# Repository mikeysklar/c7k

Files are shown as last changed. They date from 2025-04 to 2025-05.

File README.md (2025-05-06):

# c7k

c7k
===

Chording 7 Key - I2C breakout

Ultra-Thin wearable one handed keyboard which can be used with a phone, tablet, computer even from a pocket. It is a full size keybaord in seven buttons.

I2C interface means easy connectivity to modern micrcontrollers and single board computers. This allows maximum flexibility for direct to controller, HID USB or HID BLE interfacing.

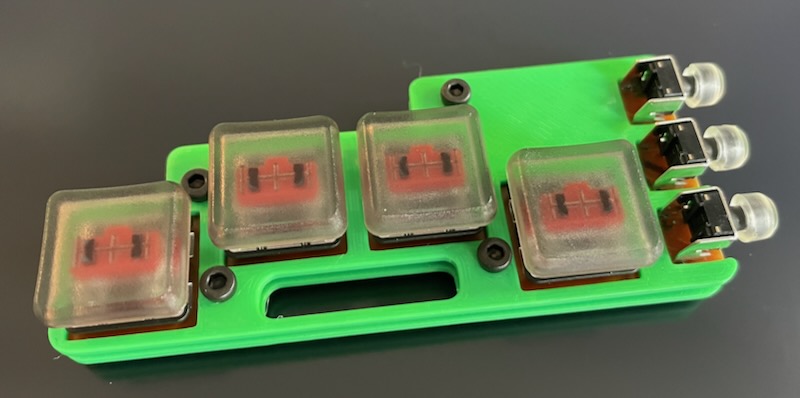
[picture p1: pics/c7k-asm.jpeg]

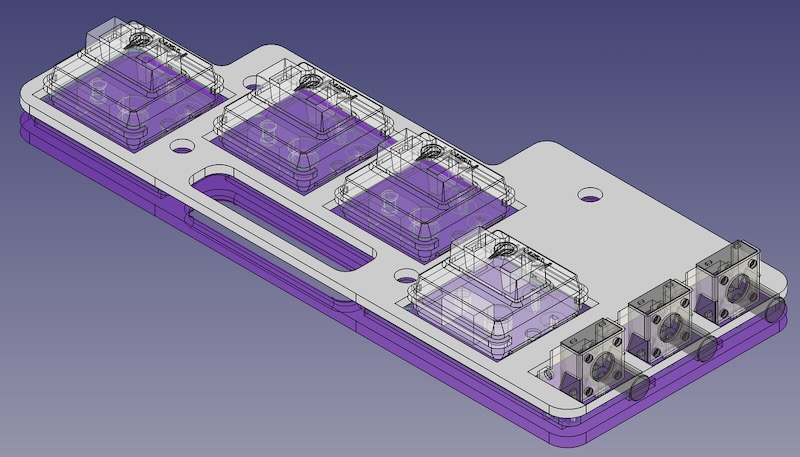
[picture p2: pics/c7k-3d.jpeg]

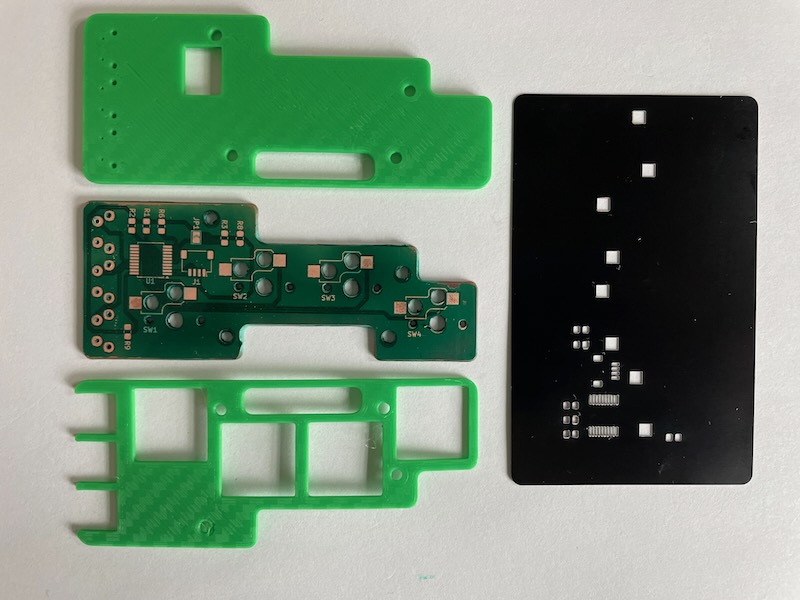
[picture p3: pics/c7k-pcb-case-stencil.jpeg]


```
| Key | Pinky | Ring | Middle | Index | Thumb |
|-----|-------|------|--------|-------|-------|
| a   | x     |      |        |       |       |
| b   | x     |      |        |       | oxo   |
| c   | x     |      |        | x     |       |
| d   |       | x    | x      | x     |       |
| e   |       |      | x      |       |       |
| f   |       | x    | x      |       | oxo   |
| g   |       |      | x      |       | oxo   |
| h   |       | x    |        |       | oxo   |
| i   |       |      | x      |       |       |
| j   |       | x    | x      | x     | oxo   |
| k   | x     |      | x      |       | oxo   |
| l   | x     |      | x      |       |       |
| m   |       |      |        | x     | oxo   |
| n   |       | x    | x      |       |       |
| o   |       | x    |        | x     |       |
| p   | x     | x    | x      |       |       |
| q   | x     | x    | x      | x     | oxo   |
| r   |       |      | x      | x     |       |
| s   | x     |      |        |       |       |
| t   | x     | x    |        |       |       |
| u   | x     | x    | x      | x     |       |
| v   | x     | x    |        |       | oxo   |
| w   |       | x    |        | x     | oxo   |
| x   | x     |      |        | x     | oxo   |
| y   |       |      | x      | x     | oxo   |
| z   | x     | x    | x      |       | oxo   |
```

```
| Key   | Pinky | Ring | Middle | Index | Thumb |
|-------|-------|------|--------|-------|-------|
| ONE   |       |      |        | x     | oox   |
| TWO   |       |      | x      |       | oox   |
| THREE |       | x    |        |       | oox   |
| FOUR  | x     |      |        |       | oox   |
| FIVE  |       |      | x      | x     | oox   |
| SIX   |       | x    | x      |       | oox   |
| SEVEN | x     | x    |        |       | oox   |
| EIGHT |       | x    |        | x     | oox   |
| NINE  | x     |      | x      |       | oox   |
| ZERO  |       | x    | x      | x     | oox   |
```

```
| Key            | Pinky | Ring | Middle | Index | Thumb |
|----------------|-------|------|--------|-------|-------|
| period         |       |      | x      |       | xoo   |
| comma          |       |      | x      | x     | xoo   |
| forward_slash  | x     | x    |        |       | xoo   |
| grave_accent   | x     | x    | x      | x     | xoo   |
| minus          | x     |      |        |       | xoo   |
| equals         |       |      | x      | x     | xoo   |
| left_bracket   | x     |      | x      |       | xoo   |
| right_bracket  | x     |      |        | x     | xoo   |
| backslash      | x     | x    |        |       | xoo   |
| semicolon      | x     | x    | x      |       | xoo   |
| quote          | x     |      | x      | x     | xoo   |
| backspace      |       | x    | x      |       | xoo   |
```

```
| Modifier        | Pinky | Ring | Middle | Index | Thumb |
|-----------------|-------|------|--------|-------|-------|
| Toggle Modifier |       |      |        |       | xxo   |
| Shift           | x     |      |        |       |       |
| Control         |       | x    |        |       |       |
| Alt             |       |      | x      |       |       |
| GUI             |       |      |        | x     |       |
```

```
| Action       | Pinky | Ring | Middle | Index | Thumb |
|--------------|-------|------|--------|-------|-------|
| Toggle Mouse |       |      |        |       | oxx   |
| Move Up      | x     |      |        |       |       |
| Move Right   |       | x    |        |       |       |
| Move Left    |       |      | x      |       |       |
| Move Down    |       |      |        | x     |       |
```

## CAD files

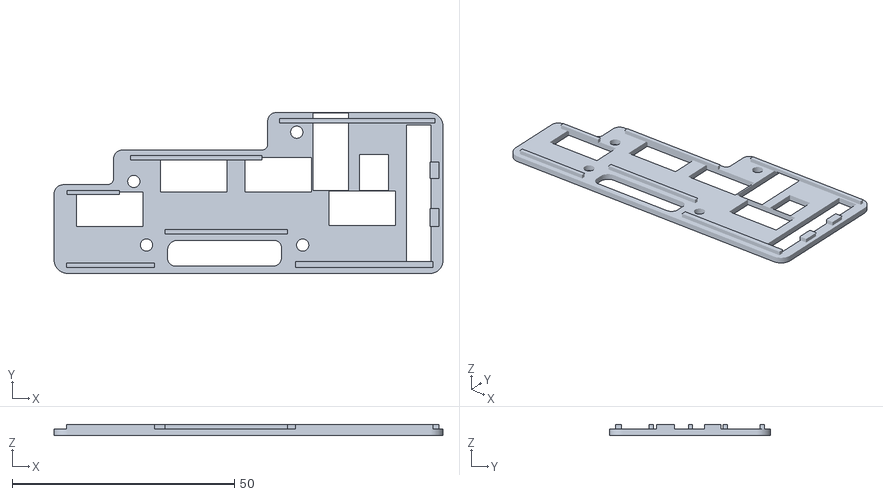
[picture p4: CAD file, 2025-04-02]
c7k-base.stl
87.6 x 36.2 x 2.50

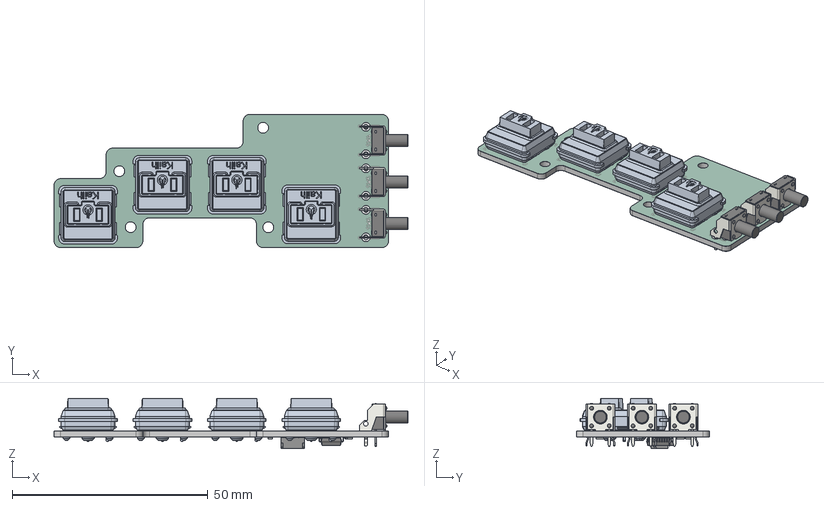
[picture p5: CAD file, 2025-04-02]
c7k.step
90.4 x 34.0 x 12.9 mm
SW_Tactile_SPST_Angled_PTS645Vx83-2LFS x 3
Kailh LP Choc Burnt Orange x 4
R_0805_2012Metric x 6
SSOP-20_5.3x7.2mm_P0.65mm
SPARKFUN_QWIIC_RIGHT_ANGLE
c7k_copper
c7k_pad
c7k_silkscreen
c7k_soldermask
c7k_PCB

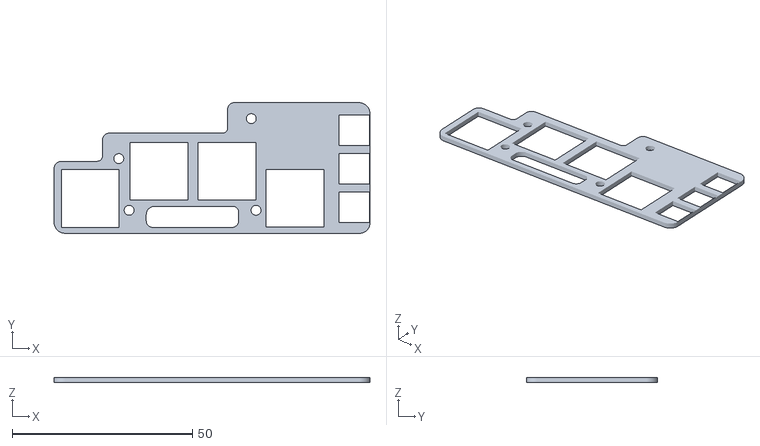
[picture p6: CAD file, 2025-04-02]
c7k-cover.stl
87.6 x 36.2 x 1.50

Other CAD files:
c7k.FCStd

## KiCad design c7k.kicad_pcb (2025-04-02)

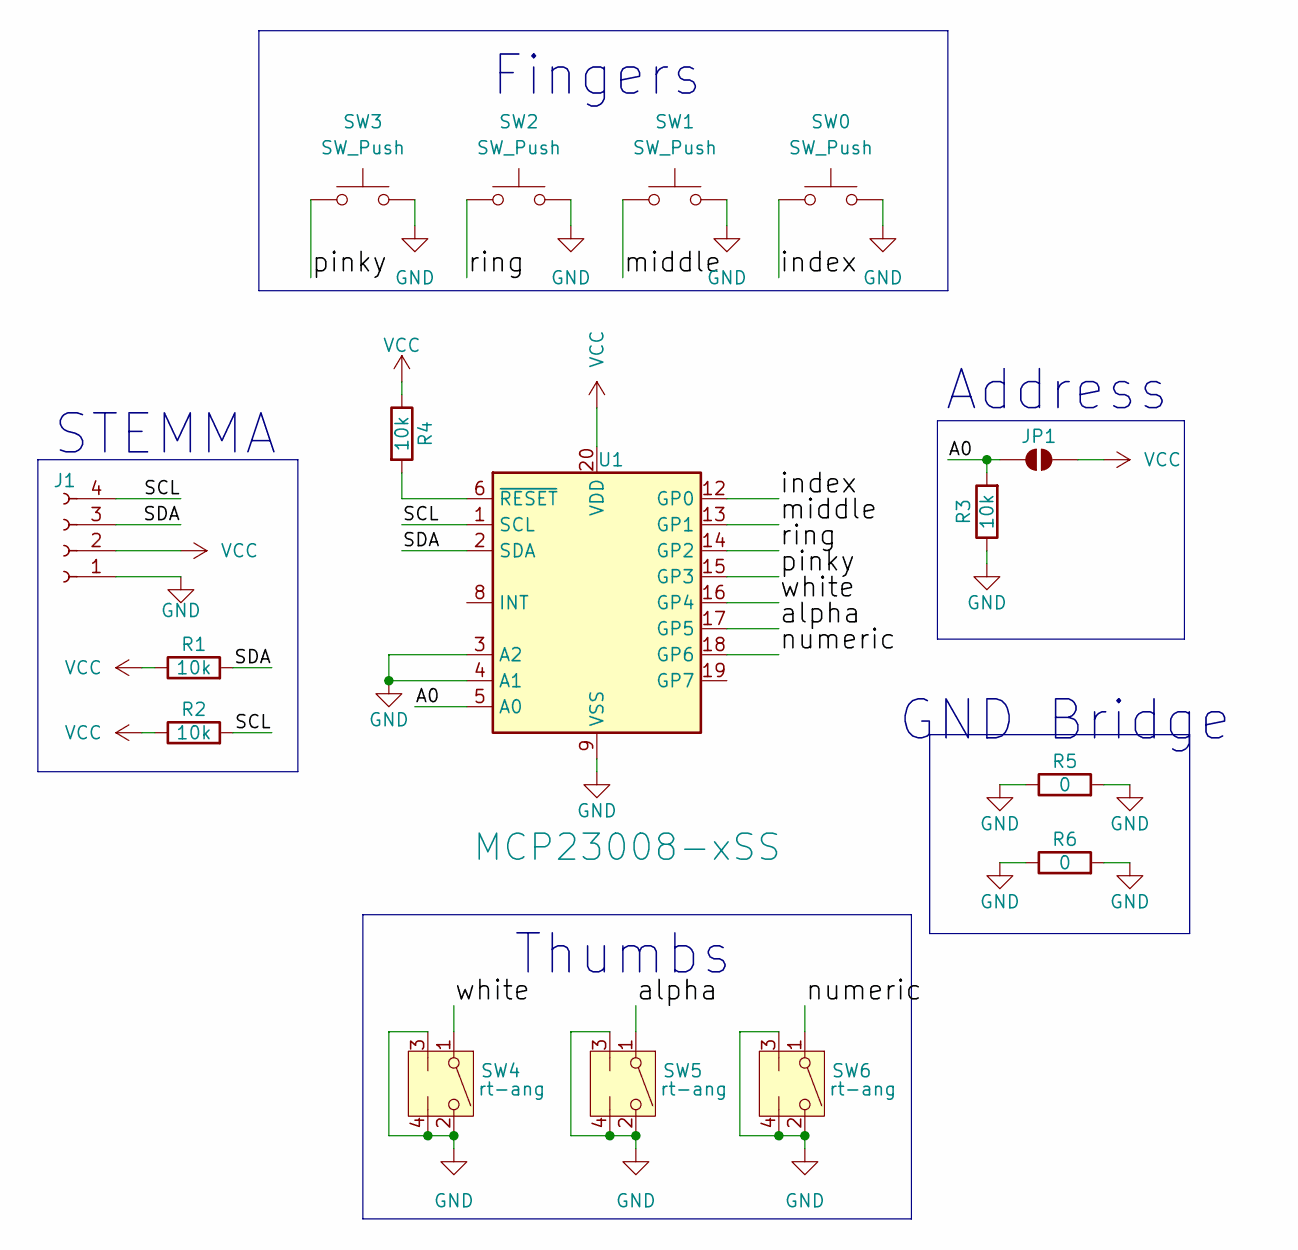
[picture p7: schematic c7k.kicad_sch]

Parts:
J1: Conn_01x04_Socket; JST_SH_SM04B-SRSS-TB_1x04-1MP_P1.00mm_Horizontal
JP1: SolderJumper_2_Open; SolderJumper-2_P1.3mm_Open_TrianglePad1.0x1.5mm
R1, R2, R3, R4: 10k; R_0805_2012Metric_Pad1.20x1.40mm_HandSolder
R5, R6: 0; R_0805_2012Metric_Pad1.20x1.40mm_HandSolder
SW0, SW1, SW2, SW3: SW_Push; Kailh_socket_PG1350
SW4, SW5, SW6: rt-ang; SW_Tactile_SPST_Angled_PTS645Vx83-2LFS
U1: MCP23008-xSS; SSOP-20_5.3x7.2mm_P0.65mm

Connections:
/A0: JP1.1 (A), R3.2, U1.5 (A0)
/SCL: J1.4, R2.2, U1.1 (SCL)
/SDA: J1.3, R1.2, U1.2 (SDA)
/alpha: SW5.1, U1.17 (GP5)
/index: SW0.1, U1.12 (GP0)
/middle: SW1.1, U1.13 (GP1)
/numeric: SW6.1, U1.18 (GP6)
/pinky: SW3.1, U1.15 (GP3)
/ring: SW2.1, U1.14 (GP2)
/white: SW4.1, U1.16 (GP4)
GND: J1.1, R3.1, R5.1, R5.2, R6.1, R6.2, SW0.2, SW1.2, SW2.2, SW3.2, SW4.2, SW4.3 (L), SW4.4 (L), SW5.2, SW5.3 (L), SW5.4 (L), SW6.2, SW6.3 (L), SW6.4 (L), U1.3 (A2), U1.4 (A1), U1.9 (VSS)
unnamed: R4.2, U1.6 (~RESET)
VCC: J1.2, JP1.2 (B), R1.1, R2.1, R4.1, U1.20 (VDD)

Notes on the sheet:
GND Bridge
Fingers
Thumbs
Address
STEMMA

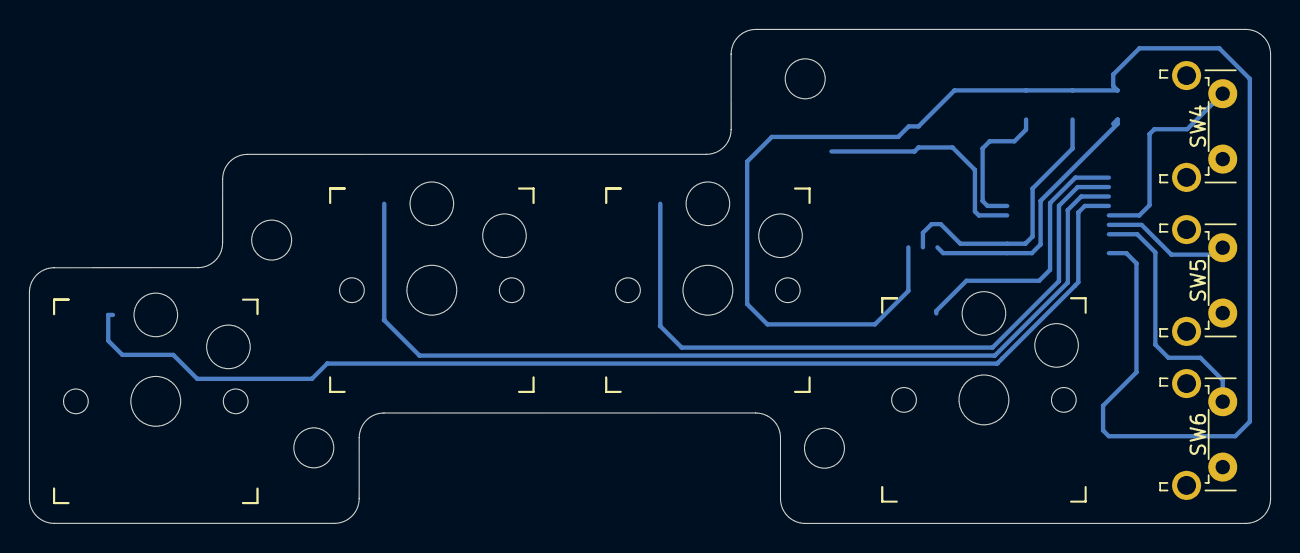
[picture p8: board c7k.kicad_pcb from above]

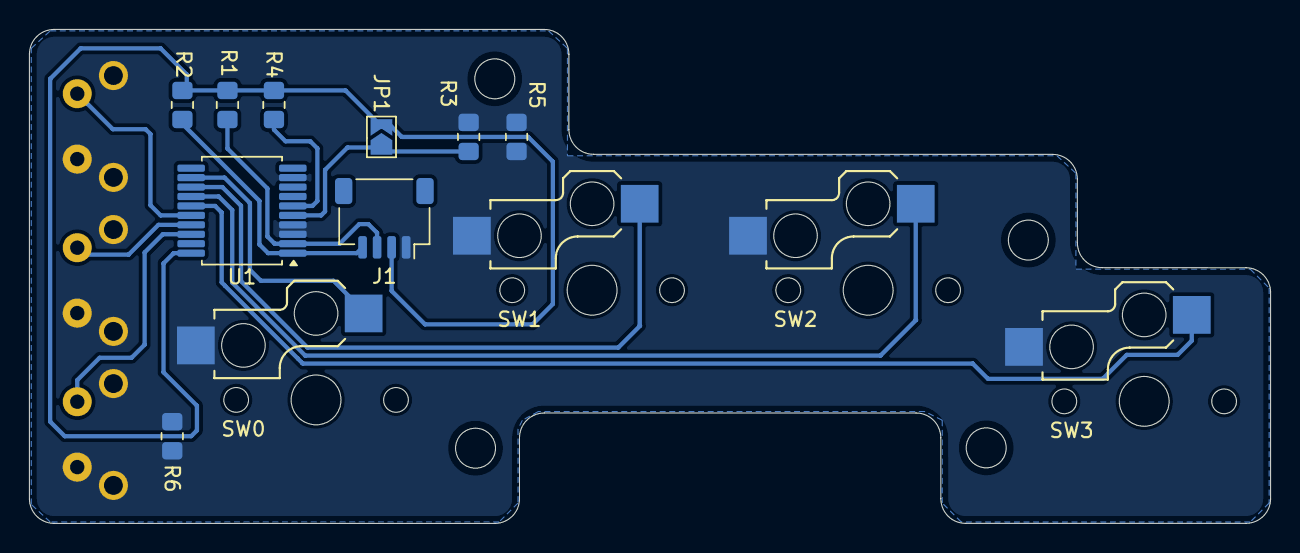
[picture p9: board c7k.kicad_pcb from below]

Board: 2 copper layers, 85.4 x 34.0 mm, 16 parts (9 on the bottom side), 13 nets.

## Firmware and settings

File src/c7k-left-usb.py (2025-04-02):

import board
import busio
import time
import digitalio
import usb_hid
from adafruit_mcp230xx.mcp23008 import MCP23008
from adafruit_hid.keyboard import Keyboard
from adafruit_hid.keycode import Keycode

# Setup I2C for MCP23008
i2c = busio.I2C(board.SCL, board.SDA)
mcp = MCP23008(i2c)

# Set up MCP23008 pins as inputs with pull-ups (using pins 0 through 6)
pins = [mcp.get_pin(i) for i in range(7)]
for pin in pins:
    pin.direction = digitalio.Direction.INPUT
    pin.pull = digitalio.Pull.UP

# Initialize USB HID keyboard
keyboard = Keyboard(usb_hid.devices)

# Map MCP23008 physical pins to our key indices (0-6)
pin_to_key_index = {
    0: 0,  # physical pin 0 → key index 0
    1: 1,  # physical pin 1 → key index 1
    2: 2,  # physical pin 2 → key index 2
    3: 3,  # physical pin 3 → key index 3
    6: 4,  # physical pin 4 → key index 4
    5: 5,  # physical pin 5 → key index 5
    4: 6   # physical pin 6 → key index 6
}

# Variables for handling key states and chords
pressed_keys = [False] * 7  # 7 keys (indexed 0-6)
pending_combo = None
last_combo_time = 0
last_hold_time = 0
last_release_time = 0

# Timing parameters
minimum_hold_time = 0.01      # Seconds keys must be held to register a chord
combo_time_window = 0.01      # Allowed time window for chord detection
cooldown_time = 0.01          # (Unused now; replaced by repeat_delay for hold behavior)
release_time_window = 0.01    # Time window to ensure keys are released before new detection
double_press_window = 0.3     # Seconds allowed between taps for a double press
repeat_delay = 0.2            # Delay between repeats when keys are held

last_backspace_time = 0
last_space_time = 0

# Define chord mappings
chords = {
    (0,): Keycode.E,
    (1,): Keycode.I,
    (2,): Keycode.A,
    (3,): Keycode.S,
    (4,): Keycode.BACKSPACE,  # Normal mapping; now only sent on double-tap
    (0, 1): Keycode.R,
    (0, 2): Keycode.O,
    (0, 3): Keycode.C,
    (1, 2): Keycode.N,
    (1, 3): Keycode.L,
    (2, 3): Keycode.T,
    (0, 5): Keycode.M,
    (1, 5): Keycode.G,
    (2, 5): Keycode.H,
    (3, 5): Keycode.B,
    (0, 4): Keycode.SPACE,      # Normal mapping; now only sent on double-tap
    (0, 1, 5): Keycode.Y,
    (0, 2, 5): Keycode.W,
    (0, 3, 5): Keycode.X,
    (1, 2, 5): Keycode.F,
    (1, 3, 5): Keycode.K,
    (2, 3, 5): Keycode.V,
    (0, 1, 2): Keycode.D,
    (1, 2, 3): Keycode.P,
    (0, 1, 2, 5): Keycode.J,
    (1, 2, 3, 5): Keycode.Z,
    (0, 1, 2, 3): Keycode.U,
    (0, 1, 2, 3, 5): Keycode.Q,
    (0, 6): Keycode.ONE,
    (1, 6): Keycode.TWO,
    (2, 6): Keycode.THREE,
    (3, 6): Keycode.FOUR,
    (0, 1, 6): Keycode.FIVE,
    (1, 2, 6): Keycode.SIX,
    (2, 3, 6): Keycode.SEVEN,
    (0, 2, 6): Keycode.EIGHT,
    (1, 3, 6): Keycode.NINE,
    (0, 3, 6): Keycode.UP_ARROW,
    (0, 1, 2, 6): Keycode.ZERO,
    (0, 1, 3, 6): Keycode.RIGHT_ARROW,
    (0, 2, 3, 6): Keycode.LEFT_ARROW,
    (1, 2, 3, 6): Keycode.ESCAPE,
    (0, 1, 2, 3, 6): Keycode.DOWN_ARROW,
    (6,): Keycode.SPACE,  # Also mapped here; double-tap takes precedence.
    (1, 4): Keycode.TAB,
    (2, 4): Keycode.PERIOD,
    (3, 4): Keycode.MINUS,
    (0, 2, 3): Keycode.SPACE,
    (0, 1, 3): Keycode.BACKSPACE,
    (2, 3, 4): Keycode.FORWARD_SLASH,
    (0, 1, 4): Keycode.ENTER,
    (0, 2, 4): Keycode.COMMA,  # Note: In the original, this chord was also set to EQUALS.
    (1, 3, 4): Keycode.LEFT_BRACKET,
    (0, 3, 4): Keycode.RIGHT_BRACKET,
    (2, 3, 4): Keycode.BACKSLASH,
    (1, 2, 4): Keycode.BACKSPACE,
    (0, 1, 3, 4): Keycode.QUOTE,
    (0, 2, 3, 4): Keycode.SEMICOLON,
    (0, 1, 2, 3, 4): Keycode.GRAVE_ACCENT
}

def check_chords():
    global pending_combo, last_combo_time, last_hold_time, last_release_time
    global last_backspace_time, last_space_time
    current_combo = tuple(i for i, pressed in enumerate(pressed_keys) if pressed)
    current_time = time.monotonic()

    if current_combo:
        # Set initial hold time if not already set.
        if last_hold_time == 0:
            last_hold_time = current_time

        if (current_time - last_hold_time) >= minimum_hold_time:
            # Special handling for the (4,) chord (BACKSPACE)
            if current_combo == (4,):
                if last_backspace_time != 0 and (current_time - last_backspace_time) <= double_press_window:
                    # Only repeat if this is a new detection or enough time has passed.
                    if pending_combo != current_combo or (current_time - last_combo_time) >= repeat_delay:
                        keyboard.press(Keycode.BACKSPACE)
                        keyboard.release_all()
                        last_backspace_time = 0  # Reset after double-tap
                        pending_combo = current_combo
                        last_combo_time = current_time
                else:
                    last_backspace_time = current_time

            # Special handling for the (6,) chord (SPACE)
            elif current_combo == (6,):
                if last_space_time != 0 and (current_time - last_space_time) <= double_press_window:
                    if pending_combo != current_combo or (current_time - last_combo_time) >= repeat_delay:
                        keyboard.press(Keycode.SPACE)
                        keyboard.release_all()
                        last_space_time = 0  # Reset after double-tap
                        pending_combo = current_combo
                        last_combo_time = current_time
                else:
                    last_space_time = current_time

            # Normal chord handling for all other chords.
            elif current_combo in chords:
                if pending_combo == current_combo:
                    if (current_time - last_combo_time) >= repeat_delay:
                        keyboard.press(chords[current_combo])
                        keyboard.release_all()
                        last_combo_time = current_time
                else:
                    keyboard.press(chords[current_combo])
                    keyboard.release_all()
                    pending_combo = current_combo
                    last_combo_time = current_time
    else:
        # Reset states when no keys are pressed.
        if last_backspace_time != 0 and (current_time - last_backspace_time > double_press_window):
            last_backspace_time = 0
        if last_space_time != 0 and (current_time - last_space_time > double_press_window):
            last_space_time = 0
        pending_combo = None
        last_hold_time = 0
        last_release_time = current_time

while True:
    # Update pressed_keys from MCP23008.
    for pin, index in pin_to_key_index.items():
        if not mcp.get_pin(pin).value:  # Active low: pressed
            if not pressed_keys[index]:
                pressed_keys[index] = True
        else:
            if pressed_keys[index]:
                pressed_keys[index] = False

    check_chords()
    time.sleep(0.05)
